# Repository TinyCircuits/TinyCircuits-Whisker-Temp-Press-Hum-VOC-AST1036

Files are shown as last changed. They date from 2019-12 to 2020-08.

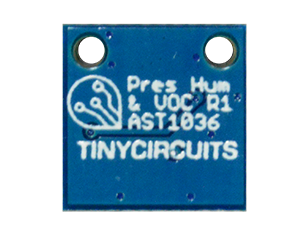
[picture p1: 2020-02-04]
images/AST1036-Learn-Photo-02.png

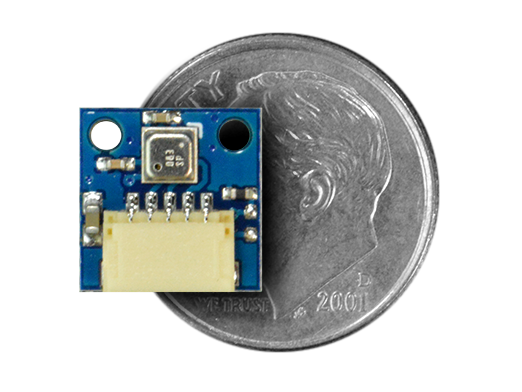
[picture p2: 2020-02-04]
images/AST1036-Product-Photo-03.png

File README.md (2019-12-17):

# TinyCircuits Wireling Temp Press Hum VOC
# AST1036 Rev1

The design files are located under design_files/ for the TinyCircuits AST1036 Rev 1 PCB. This is a Wireling board which features the BME680 Sensor that is a 4-in-1 sensor including the ability to measure temperature, barometric pressure, humidity, and gas.

Format is in Cadsoft Eagle format - Eagle version 6.2 was used for the original design.

For more infomation on this, check out the product page at TinyCircuits.com

# License:

Design by TinyCircuits.
All design files are released under the Creative Commons Attribution Share-Alike 3.0 License, see the following link for details: http://creativecommons.org/licenses/by-sa/3.0

All text above must be included in any redistribution or derived design

This project uses designs and concepts developed as part of the Arduino project and the LilyPad project.  The TinyCircuits design files themselves (schematics, PCB and libraries) are not directly derived from these works' design files and have been created new, however the concepts and basic architecture behind the TinyDuino and TinyLily products are derived and we thank the hard work of the organizations below for their contributions to open-source hardware:
  
Original Arduino Uno Design by Team Arduino

LilyPad Arduino Design by Leah Buechley and Sparkfun Electronics

Please support the open-source hardware community

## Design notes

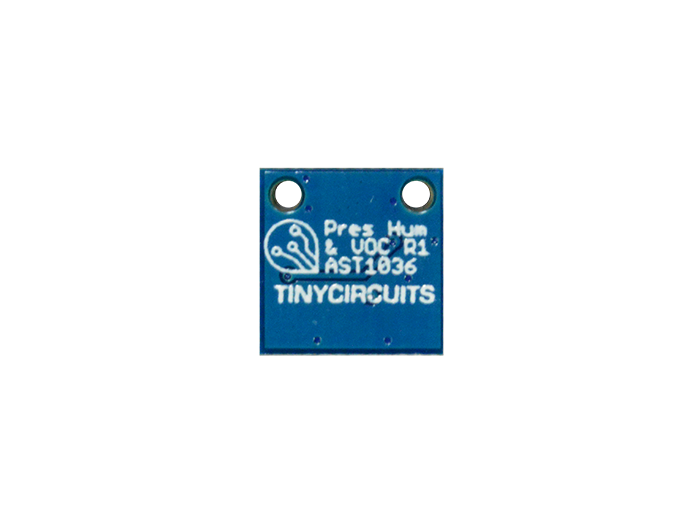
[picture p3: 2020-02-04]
images/AST1036-Product-Photo-02.png

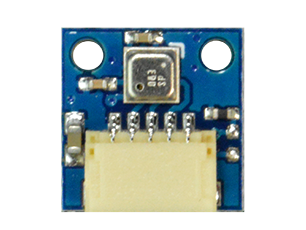
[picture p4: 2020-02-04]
images/AST1036-Learn-Photo-01.png

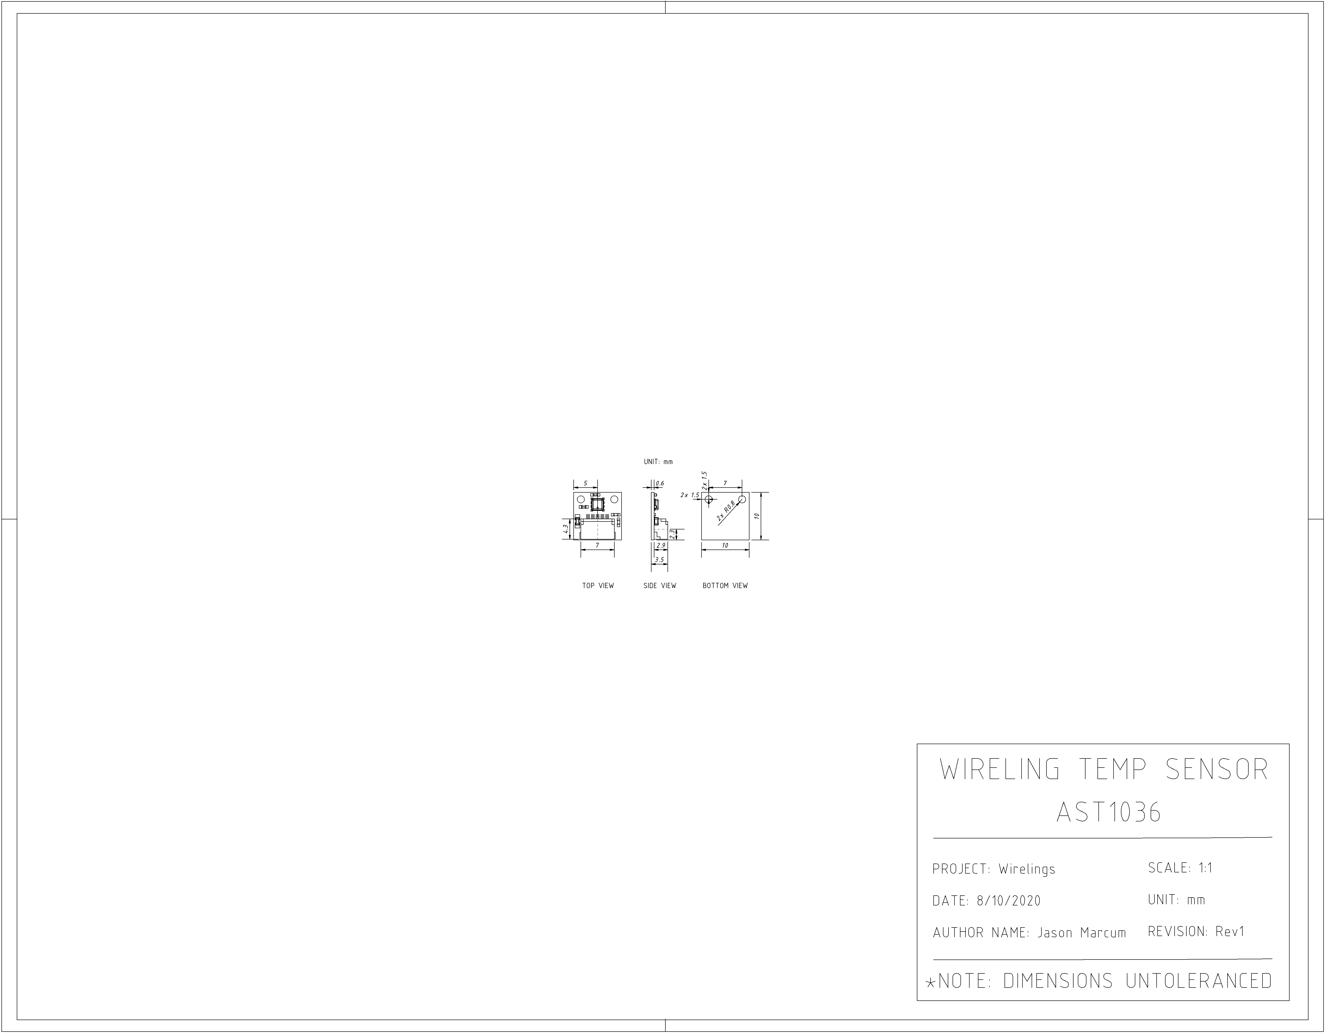
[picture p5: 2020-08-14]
cad/Wireling_TEMP_AST1036_REV2-DETAILED_DRAWING-PNG.png

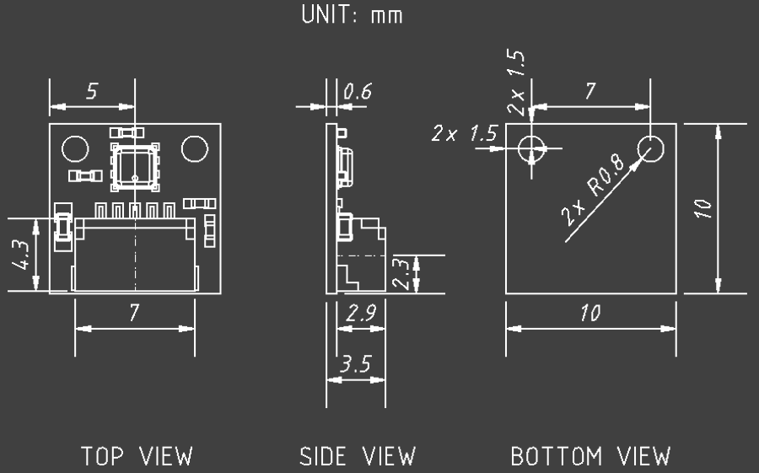
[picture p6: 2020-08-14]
cad/Wireling_TEMP_AST1036_REV2-DETAILED_DRAWING_COMPACT-PNG.png

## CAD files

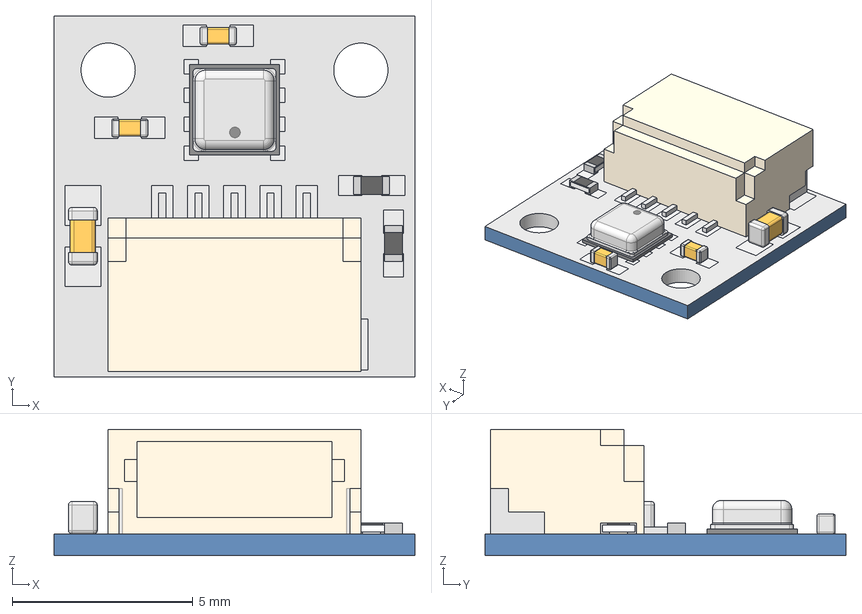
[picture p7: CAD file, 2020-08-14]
cad/Wireling_TEMP_AST1036_REV2-STEP.step
10.0 x 10.0 x 3.50 mm

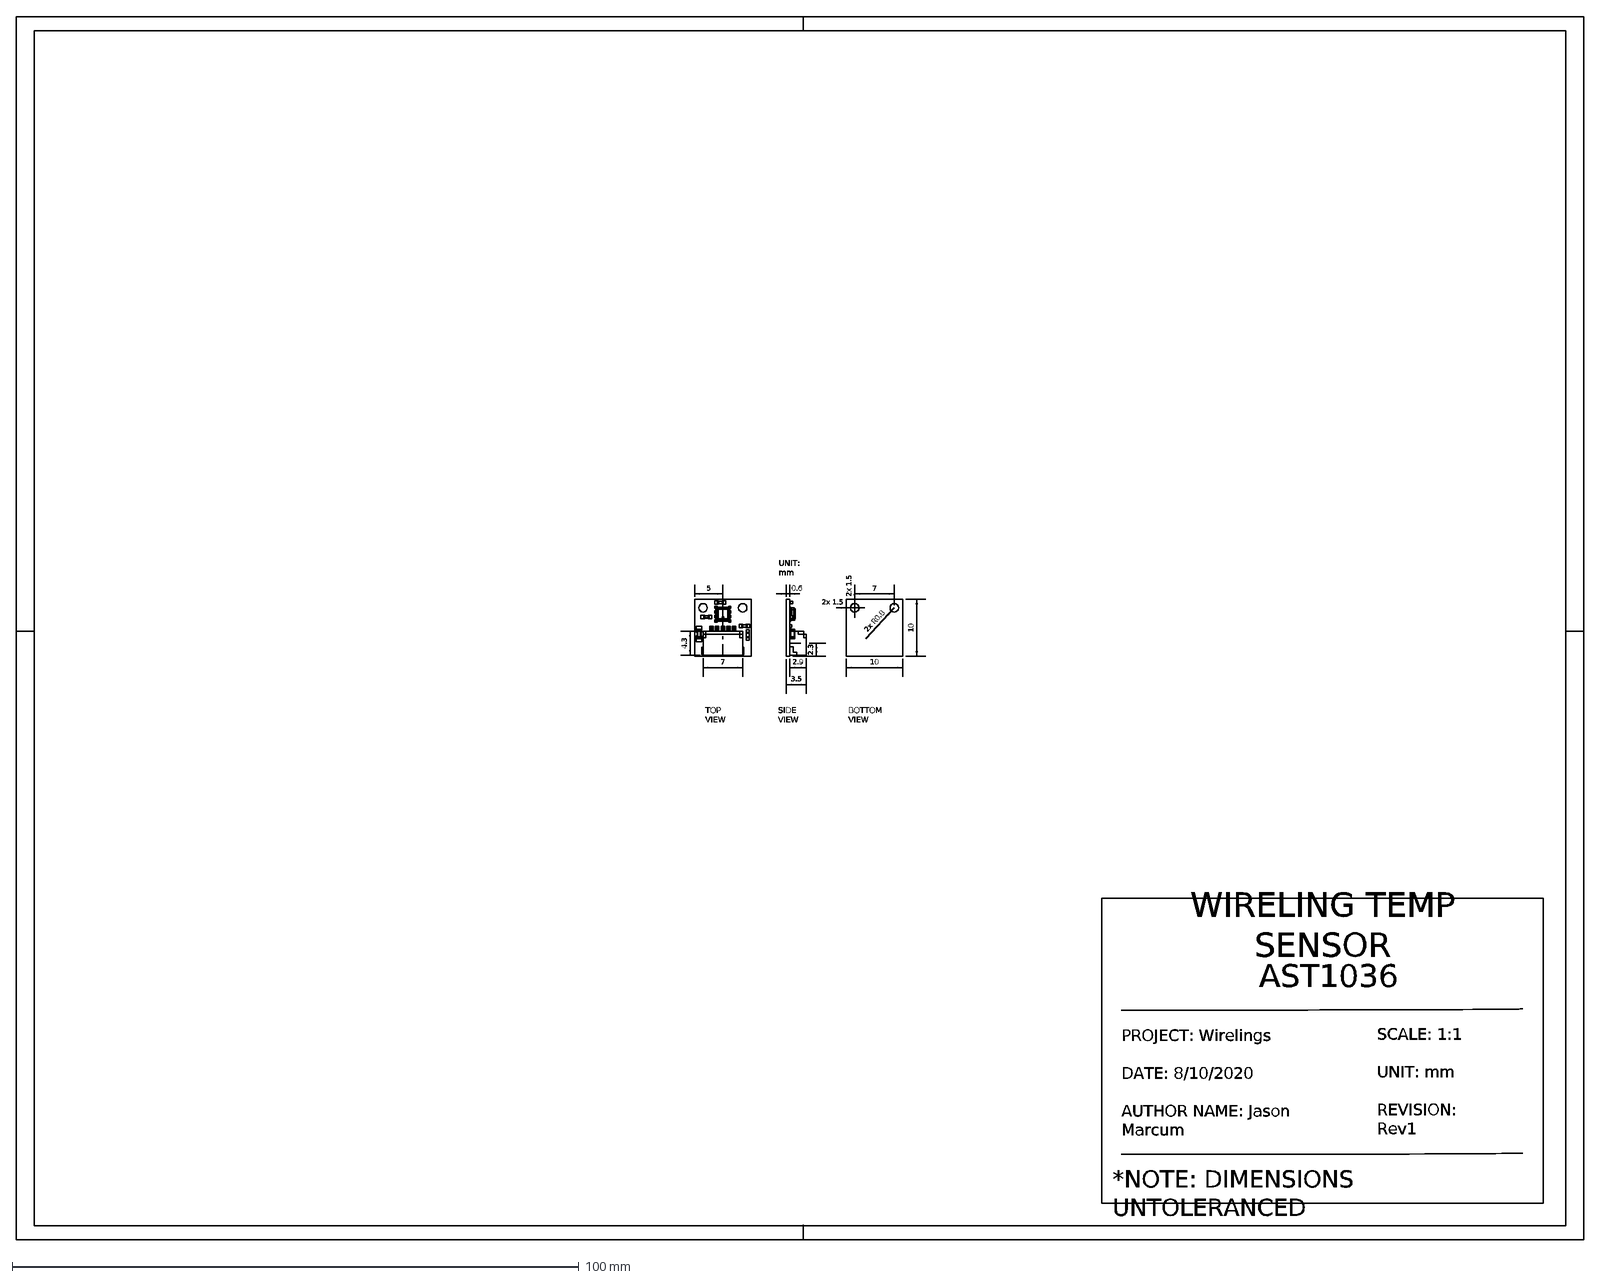
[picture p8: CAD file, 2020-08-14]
cad/Wireling_TEMP_AST1036_REV2-DETAILED_DRAWING-DXF.dxf
*NOTE: DIMENSIONS UNTOLERANCED
SCALE: 1:1 UNIT: mm REVISION: Rev1
TOP VIEW
BOTTOM VIEW
SIDE VIEW
UNIT: mm
7
4.3
5
2.9
3.5
0.6
2.3
2x 1.5
2x R0.8
10
WIRELING TEMP SENSOR
AST1036
PROJECT: Wirelings DATE: 8/10/2020 AUTHOR NAME: Jason Marcum

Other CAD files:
cad/Wireling_TEMP_AST1036_REV2-STL.stl
cad/Wireling_TEMP_AST1036_REV2-IGES.iges

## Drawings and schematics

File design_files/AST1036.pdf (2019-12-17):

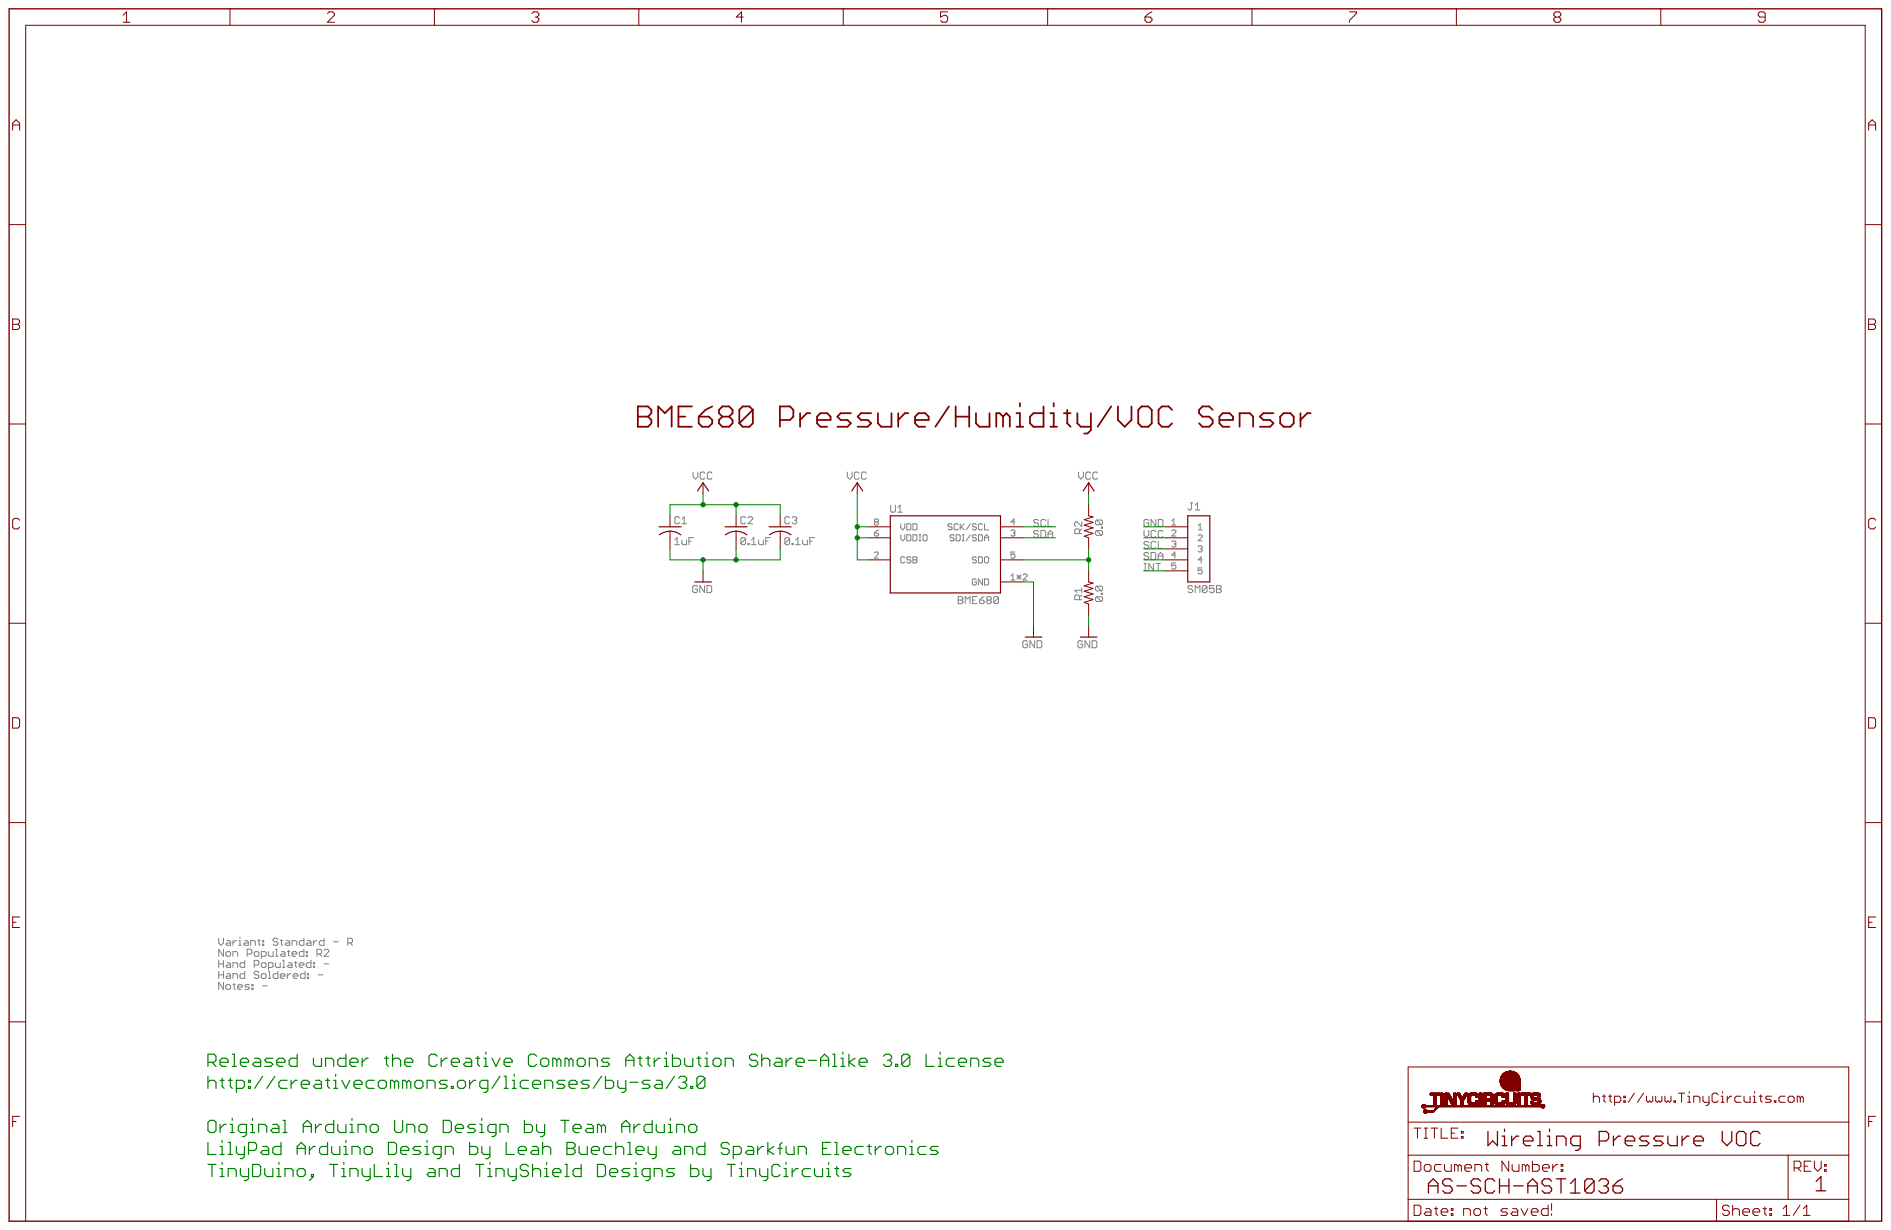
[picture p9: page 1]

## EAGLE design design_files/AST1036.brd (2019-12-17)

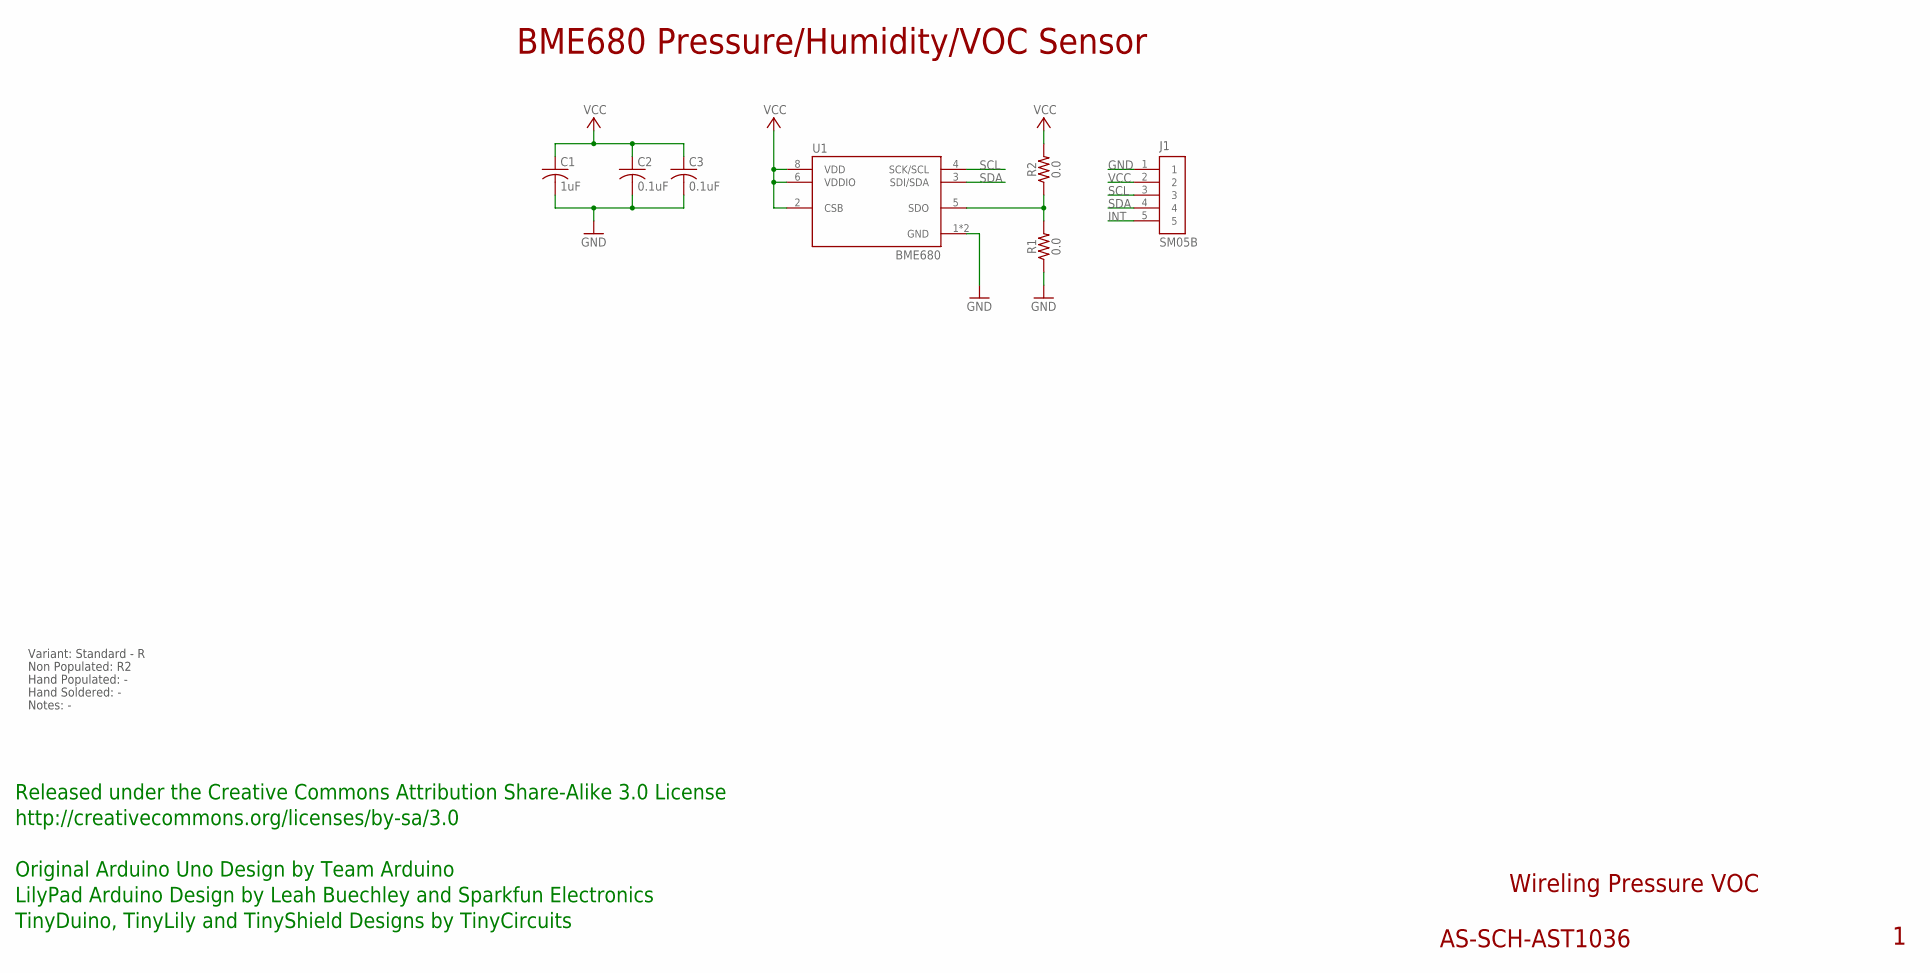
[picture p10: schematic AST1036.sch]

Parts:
C1: 1uF; C0603; PARTNO AS-ITM-00410
C2: 0.1uF; C0402
C3: 0.1uF; C0402; PARTNO AS-ITM-00008
J1: SM05B; JST_SH_5X1_EDGE
R1: 0.0; 0402
R2: 0.0; 0402; PARTNO AS-ITM-00076
U1: BME680

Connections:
GND: C1.2, C2.2, C3.2, J1.1, R1.1, U1.1 (GND), U1.7 (GND)
INT: J1.5
unnamed: R1.2, R2.1, U1.5 (SDO)
SCL: J1.3, U1.4 (SCK/SCL)
SDA: J1.4, U1.3 (SDI/SDA)
VCC: C1.1, C2.1, C3.1, J1.2, R2.2, U1.2 (CSB), U1.6 (VDDIO), U1.8 (VDD)

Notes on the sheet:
Wireling Pressure VOC
AS-SCH-AST1036
BME680 Pressure/Humidity/VOC Sensor
Released under the Creative Commons Attribution Share-Alike 3.0 License
http://creativecommons.org/licenses/by-sa/3.0
Original Arduino Uno Design by Team Arduino
TinyDuino, TinyLily and TinyShield Designs by TinyCircuits
LilyPad Arduino Design by Leah Buechley and Sparkfun Electronics
Non Populated: R2
Hand Populated: -
Hand Soldered: -
Notes: -
Variant: Standard - R

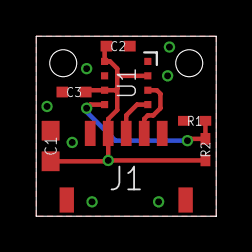
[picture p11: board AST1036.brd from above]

Board: 2 copper layers, 10.0 x 10.0 mm, 8 parts (0 on the bottom side), 5 nets.

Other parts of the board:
U$1: DOCFIELD-TINYCIRCUITS-PCB

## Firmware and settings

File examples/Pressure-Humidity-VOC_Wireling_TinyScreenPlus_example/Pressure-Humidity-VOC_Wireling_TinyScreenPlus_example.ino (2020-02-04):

/*************************************************************************
   BME680 Wireling Tutorial:
   Print the temperature(C), altitude, pressure(hPa), and humidity(%)
   readings the BME680 sensor is capable of reading

   Hardware by: TinyCircuits
   BME680 Library by: Adafruit
   Code by: Laveréna Wienclaw and Zachary Lee for TinyCircuits

   Initiated: Mon. 11/29/2017
   Updated: Tue. 07/31/2019
 ************************************************************************/

// This library is used for communication with I2C devices, such as the BME680 board
#include <Wire.h>
#include <Wireling.h>

// This library is used to print sensor values to a TinyScreen
#include <TinyScreen.h>

// These libraries are used to interface with the BME680 Sensor
#include "Adafruit_Sensor.h"
#include "Adafruit_BME680.h"

// Global Sensor Variables
#define SEALEVELPRESSURE_HPA (1013.25) // used to find approximate altitude 
Adafruit_BME680 bme; // I2C

// TinyScreen Global Variables
TinyScreen display = TinyScreen(TinyScreenPlus);
int background = TS_8b_Black; // sets the background color to black

// Used to control how often sensor values are updated in the main loop()
unsigned long delayTime = 1000;
const bool displayAlt = false; // if set to true, altitude will be displayed on the TinyScreen+ instead of gas 

void setup() {
  SerialUSB.begin(9600); // Bandwidth for our communication
  // Print to Serial Monitor
  // You can pass flash-memory based strings to SerialUSB.print() by wrapping them with F().
  // This means you're using flash memory instead of RAM to print stuff
  SerialUSB.println(F("BME680 test"));

  Wire.begin();
  Wireling.begin();
  Wireling.selectPort(0); // The adapter board has 4 different ports (0-3),

  // This is the setup used to initialize the TinyScreen's appearance
  display.begin();
  display.setBrightness(15);
  display.setFlip(true);
  display.setFont(thinPixel7_10ptFontInfo);
  display.fontColor(TS_8b_White, background);

  // Set the cursor to the following coordinates before it prints "BME680 Test"
  display.setCursor(0, 0);
  display.print("BME680 Test");

  // If the bme sensor is not found, throw statement and stop program
  // If you end up here, check to make sure your value in selectPort() is correct!
  if (!bme.begin(0x76)) {
    display.setCursor(12, 12);
    display.print("No Sensor!");  // Printed to TinyScreen
    SerialUSB.println("Could not find a valid BME680 sensor, check wiring!"); // Printed to Serial Monitor
    while (1); // loop forever, because the rest of the program means nothing without the sensor
  }
  // Set up oversampling and filter initialization
  bme.setTemperatureOversampling(BME680_OS_8X);
  bme.setHumidityOversampling(BME680_OS_2X);
  bme.setPressureOversampling(BME680_OS_4X);
  bme.setIIRFilterSize(BME680_FILTER_SIZE_3);
  bme.setGasHeater(320, 150); // 320*C for 150 ms

  SerialUSB.println("-- Default Test --");
  SerialUSB.println();
}

// Forever looping the following logic
void loop() {
  if (! bme.performReading()) {
    SerialUSB.println("Failed to perform reading :(");
    return;
  }
  printValues(); // Print to serial monitor
  printScreen(); // Print to TinyScreen
  delay(delayTime); // How often values are updated and printed
}

// This function prints out the values from the sensor to the Serial Monitor
void printValues() {
  SerialUSB.print("Temperature = ");
  SerialUSB.print(bme.readTemperature());
  SerialUSB.println(" *C");

  SerialUSB.print("Pressure = ");
  SerialUSB.print(bme.readPressure() / 100.0F);
  SerialUSB.println(" hPa");

  SerialUSB.print("Approx. Altitude = ");
  SerialUSB.print(bme.readAltitude(SEALEVELPRESSURE_HPA));
  SerialUSB.println(" m");

  SerialUSB.print("Humidity = ");
  SerialUSB.print(bme.readHumidity());
  SerialUSB.println(" %");

  SerialUSB.print("Gas = ");
  SerialUSB.print(bme.gas_resistance / 1000.0);
  SerialUSB.println(" KOhms");

  SerialUSB.println();
}

// This function prints out the values from the sensor to a TinyScreen screen
void printScreen() {
  display.setCursor(0, 12);
  display.print("Temp: ");
  display.print(bme.readTemperature());
  display.println(" C");

  display.setCursor(0, 24);
  display.print("Pres: ");
  display.print(bme.readPressure() / 100.0F);
  display.println(" hPa");

  if (displayAlt) {
    display.setCursor(0, 36);
    display.print("Alt: ");
    display.print(bme.readAltitude(SEALEVELPRESSURE_HPA));
    display.println(" m");
  }
  else {
    display.setCursor(0, 36);
    display.print("Gas: ");
    display.print(bme.gas_resistance / 1000.0);
    display.println(" kOhms");
  }

  display.setCursor(0, 48);
  display.print("Hum: ");
  display.print(bme.readHumidity());
  display.println(" %");

  display.println();
}

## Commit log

2019-12-17 updated documentation
    [AST1036.brd, AST1036.sch]
2020-01-15 remove old schematic
2020-08-14 Add CAD data
    [Wireling_TEMP_AST1036_REV2-DETAILED_DRAWING-DXF.dxf, Wireling_TEMP_AST1036_REV2-IGES.iges, Wireling_TEMP_AST1036_REV2-STEP.step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]
